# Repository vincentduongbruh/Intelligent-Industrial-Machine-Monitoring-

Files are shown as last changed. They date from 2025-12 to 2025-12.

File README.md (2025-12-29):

# Intelligent Industrial Motor Monitoring

**Real-Time Fault Detection Using Current, Vibration, and Temperature Sensing**

This project presents an intelligent motor health monitoring system designed to detect early-stage electrical and mechanical faults in industrial motors. The system continuously measures **3-phase current**, **vibration**, and **temperature**, analyzes these signals in real time, and visualizes motor health indicators through a graphical user interface (GUI).

The work was conducted in collaboration with **NASA Ames Research Center** and builds upon prior research on generalized fault detection using the **Filtered Park’s Vector Approach (FPVA)**. While traditional fault-detection methods often remain confined to offline analysis or simulation, this project focuses on a **deployable, sensor-driven monitoring platform** suitable for real-world industrial environments.

---

## Motivation

Induction motors account for approximately **90% of electrically driven industrial machinery**, including:
- Manufacturing robots
- CNC machines
- Conveyors
- HVAC systems
- Aerospace actuators and pumps

Despite their ubiquity, motor faults such as **bearing wear**, **shaft misalignment**, **gear damage**, and **electrical phase imbalance** often go undetected until catastrophic failure. These faults manifest as changes in:
- Current signatures
- Vibration spectra
- Operating temperature

This project bridges the gap between **fault-detection algorithms** and **physical monitoring infrastructure**, enabling early detection and improved system reliability.

---

## System Overview

The system is composed of three primary subsystems:

1. **Temperature & Vibration Sensing PCB**
2. **3-Phase Current Sensing PCB**
3. **Data Processing Server and GUI**

Sensor data is transmitted to the processing server via a combination of **USB** and **Bluetooth Low Energy (BLE)** links.

> Note: Due to limited access to industrial induction motors, testing was performed using **ESC-driven brushless motors**. While this changes the expected current waveforms, the monitoring approach remains applicable to industrial motors and VFD-driven systems.

---

## Hardware Architecture

### Sensors
- **Temperature**: Dual SHT30 temperature sensors mounted near motor windings
- **Vibration**: Dual MPU6500 IMUs measuring linear acceleration
- **Current**: Non-invasive current transformer measuring 3-phase current

### Electronics
- **ESP32 Microcontrollers**
  - One ESP32 for temperature & vibration sensing
  - One ESP32 for high-speed current acquisition

### Physical Testing Rig
- Custom **3D-printed rig** for:
  - Mechanical stability
  - Consistent sensor placement
  - Repeatable experiments

---

## Embedded Software

### Sensor Drivers
- Custom I2C drivers for temperature and IMU sensors
- Register-level configuration based on manufacturer datasheets
- Real-time data acquisition

### Sensor Calibration
- **Affine sensor model** used to correct bias and sensitivity
- Gravity-based calibration for IMUs
- Known-reference calibration for temperature sensors

### Signal Conditioning
- **Exponential Moving Average (EMA) low-pass filtering**
  - Reduces high-frequency noise
  - Lightweight and suitable for real-time embedded systems

### Communication
- **BLE (1 kHz)**: Temperature and vibration data
- **USB (10 kHz)**: Phase-accurate 3-phase current data
  - Chosen to avoid wireless latency and phase misalignment

---

## Data Processing

### Park’s Vector Approach
- Converts 3-phase currents into the rotating **d–q reference frame**
- Enables fault detection through geometric patterns in the id–iq plane

Under ideal conditions:
- Healthy motor → circular Park’s Vector trajectory
- Faulted motor → distorted or asymmetric trajectory

For ESC-driven motors:
- Healthy motor → six-pointed star pattern
- Phase fault → collapsed or triangular pattern

The system adapts the interpretation of Park’s Vector results based on the motor drive method.

---

## Graphical User Interface (GUI)

The GUI provides real-time visualization of:

1. **3-Phase Current Waveforms**
2. **Filtered Park’s Vector Plot**
3. **Vibration (Time + Frequency Domain)**
   - RMS vibration
   - FFT-based frequency analysis
4. **Temperature Monitoring**

Threshold-based alerts notify the user of potential electrical or mechanical faults.

---

## Testing and Validation

Fault conditions were intentionally introduced to validate system behavior:
- **Phase imbalance** via diode-induced waveform distortion
- **Mechanical vibration** using off-center rotating loads
- **Thermal stress** via high-throttle motor operation

The system consistently distinguished healthy and faulted operating states across current, vibration, and temperature modalities.

---

## Challenges and Limitations

- **Wireless latency** caused phase misalignment (resolved by USB current transmission)
- **ESC-driven motors** produce non-sinusoidal waveforms
- **High sampling rates** (≥10 kHz) required for accurate current analysis
- Limited access to industrial induction motors for final validation

---

## Future Work

- Deploy and validate system on industrial induction motors
- Apply machine learning for **multi-class fault classification**
- Extract higher-level features from current, vibration, and thermal data
- Improve fault localization and severity estimation

---

## Team

- **Nick Bui**
- **Mohamed Homsi**
- **Aashrith Beesabathuni**
- **Vincent Duong**
- **Carter Chen**

---

## Acknowledgements

We thank:
- Professor Dutta
- Paul De La Sayette
- Matteo Guarrera
- Dr. Rodney Martin
- Isak Bolin (NASA Ames Research Center)

for their guidance and foundational research support.

---

## References

- Bolin, I. *Generalized Fault Detection of Broken Rotor Bars in Induction Motors*, Uppsala University, 2024.

---

## To run GUI on Raspberry Pi or Laptop: 
<pre>cd src/raspberry_pi </pre>
<pre>python -m venv env</pre>
<pre>source env/bin/activate</pre>
<pre>pip install -r requirements.txt</pre>
<pre>python gui.py</pre>

## Troubleshooting FAQ:
#### BLE Connection Failing: 
- Ctrl+C to terminate
- Reset ESP 1
- <pre>python gui.py</pre>
#### CT Data Missing:
- Ctrl+C to terminate
- Reset ESP2
- <pre>python gui.py</pre>

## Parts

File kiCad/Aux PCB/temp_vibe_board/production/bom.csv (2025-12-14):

Designator | Footprint | Quantity | Value | LCSC Part #
C1, C2, C3, C4 | 0805 | 4 | 0.1 uF
J1, J9 | PinHeader_1x04_P2.54mm_Horizontal | 2 | Conn_01x04_Pin
R1, R2, R3, R4 | 0805 | 4 | 4.7 K
U1 | MODULE_DEV-13907 | 1 | DEV-13907
U2, U6 | MPU6500 | 2 | MPU-6500

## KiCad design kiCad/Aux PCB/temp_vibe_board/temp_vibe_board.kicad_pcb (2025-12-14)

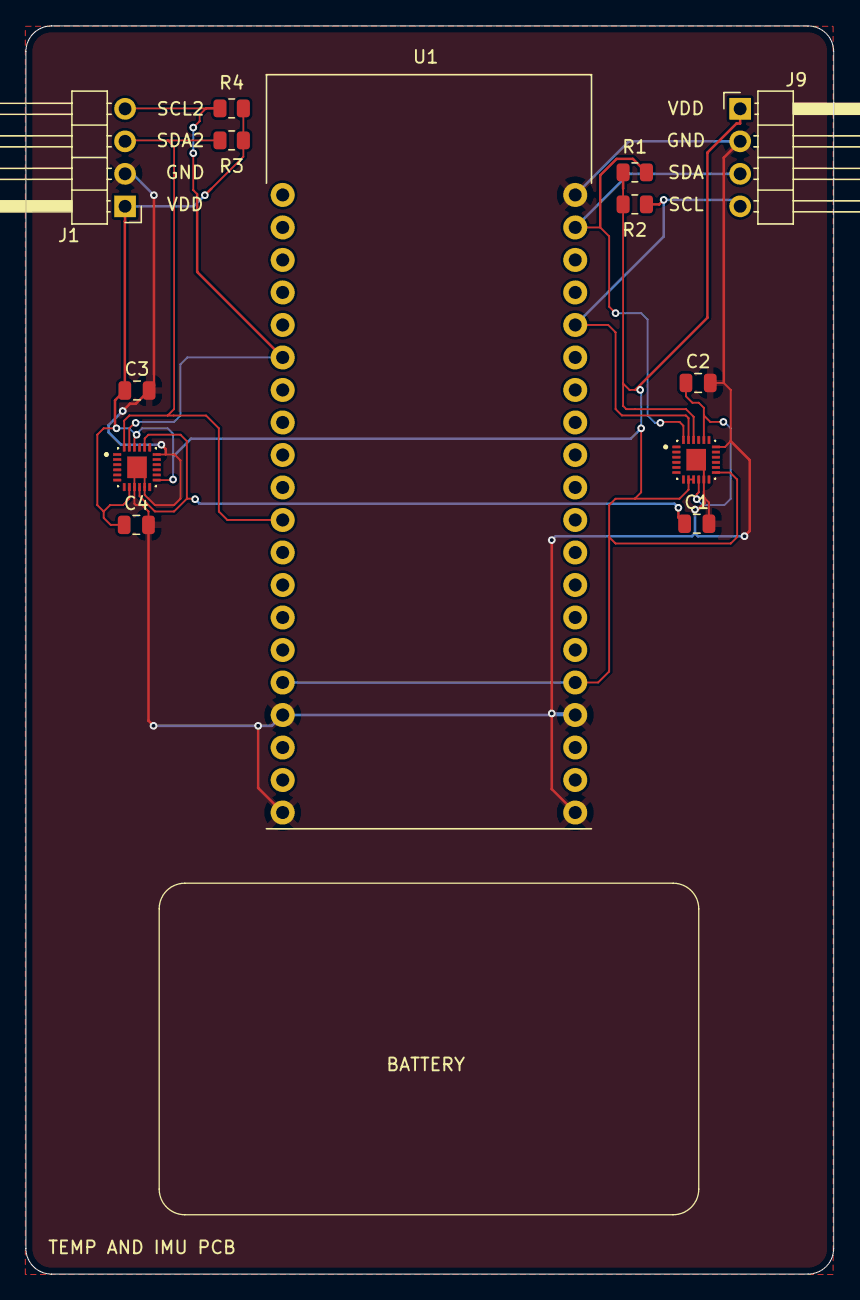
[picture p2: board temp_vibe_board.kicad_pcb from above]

Board: 2 copper layers, 63.1 x 97.5 mm, 13 parts (0 on the bottom side), 8 nets.

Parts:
C1, C2, C3, C4: 0.1 uF; C_0805_2012Metric
J1, J9: Conn_01x04_Pin; PinHeader_1x04_P2.54mm_Horizontal
R1, R2, R3, R4: 4.7 K; R_0805_2012Metric
U1: DEV-13907; MODULE_DEV-13907
U2, U6: MPU-6500; MPU6500

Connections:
GND: C1.2, C2.2, C3.2, C4.2, J1.2, J9.2, U1.J1_1 (GND), U1.J1_4 (GND), U1.J2_1 (GND), U1.J2_4 (GND), U1.J2_20 (GND), U2.11 (FSYNC), U2.18 (GND), U2.25 (EXP), U6.9 (AD0/SDO), U6.11 (FSYNC), U6.18 (GND), U6.25 (EXP)
unnamed: C2.1, U2.10 (REGOUT), U2.20 (RESV_2)
unnamed: C1.1, U6.10 (REGOUT), U6.20 (RESV_2)
SCL: J9.4, R1.2, U1.J2_16 (U0_RTS/V_SPI_WP/GPIO22/SCL/22), U2.23 (SCL/SCLK)
SCL2: J1.4, R4.2, U1.J1_15 (TOUCH8/ADC1_5/GPIO33/XTAL32/33), U6.23 (SCL/SCLK)
SDA: J9.3, R2.2, U1.J2_19 (V_SPI_HD/GPIO21/SDA/21), U2.24 (SDA/SDI)
SDA2: J1.3, R3.2, U1.J1_10 (TOUCH7/ADC2_7/GPIO27/27), U6.24 (SDA/SDI)
VDDIO: C3.1, C4.1, J1.1, J9.1, R1.1, R2.1, R3.1, R4.1, U1.J1_5 (3.3V/3V3), U1.J2_5 (3.3V/3V3), U2.8 (VDDIO), U2.9 (AD0/SDO), U2.13 (VDD), U2.22 (NCS), U6.8 (VDDIO), U6.13 (VDD), U6.22 (NCS)

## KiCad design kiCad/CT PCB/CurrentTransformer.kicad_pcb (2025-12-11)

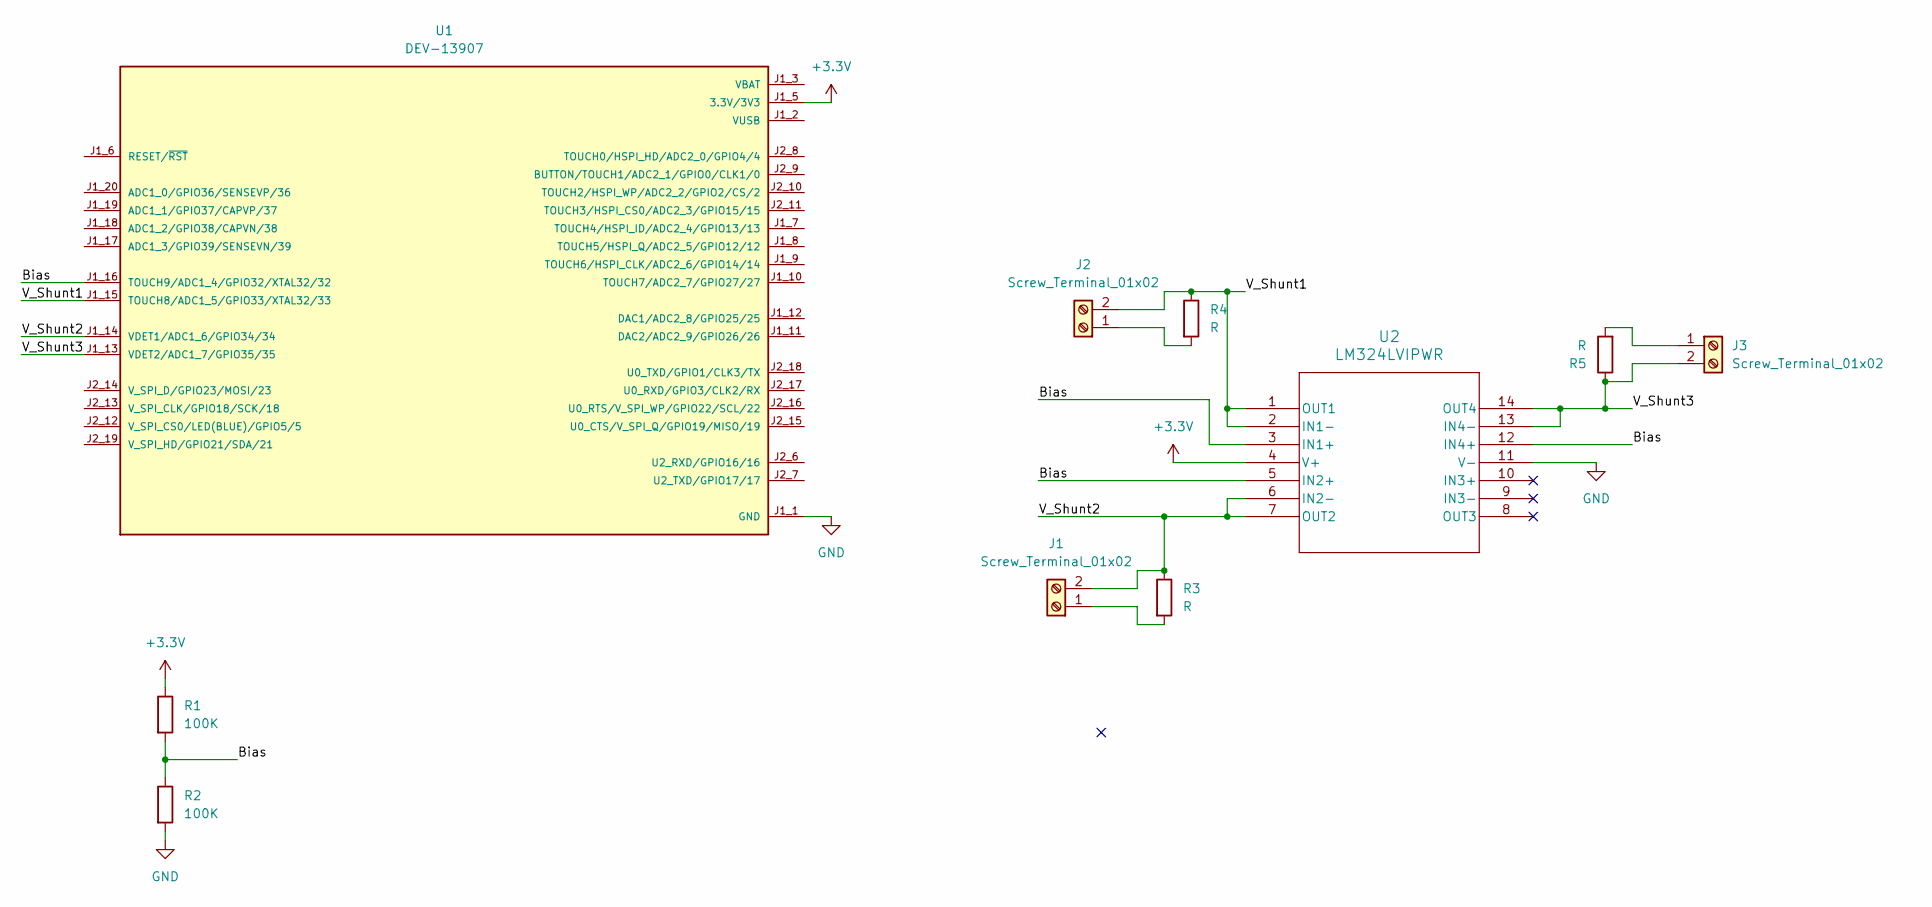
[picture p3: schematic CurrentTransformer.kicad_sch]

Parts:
J1, J2, J3: Screw_Terminal_01x02; OST_OSTTE020104
R1, R2: 100K; R_0603_1608Metric
R3, R4, R5: R; R_Axial_DIN0207_L6.3mm_D2.5mm_P10.16mm_Horizontal
U1: DEV-13907; MODULE_DEV-13907; PARTREV V10
U2: LM324LVIPWR; PW14_TEX-L

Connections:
+3.3V: R1.1, U1.J1_5 (3.3V/3V3), U1.J2_5 (3.3V/3V3), U2.4 (V+)
/Bias: R1.2, R2.1, U1.J1_16 (TOUCH9/ADC1_4/GPIO32/XTAL32/32), U2.3 (IN1+), U2.5 (IN2+), U2.12 (IN4+)
/V_Shunt1: J2.2, R4.1, U1.J1_15 (TOUCH8/ADC1_5/GPIO33/XTAL32/33), U2.1 (OUT1), U2.2 (IN1-)
/V_Shunt2: J1.2, R3.1, U1.J1_14 (VDET1/ADC1_6/GPIO34/34), U2.6 (IN2-), U2.7 (OUT2)
/V_Shunt3: J3.2, R5.1, U1.J1_13 (VDET2/ADC1_7/GPIO35/35), U2.13 (IN4-), U2.14 (OUT4)
GND: R2.2, U1.J1_1 (GND), U1.J1_4 (GND), U1.J2_1 (GND), U1.J2_4 (GND), U1.J2_20 (GND), U2.11 (V-)
unnamed: J1.1, R3.2
unnamed: J2.1, R4.2
unnamed: J3.1, R5.2
VBAT: U1.J1_3 (VBAT), U1.J2_3 (VBAT)
VUSB: U1.J1_2 (VUSB), U1.J2_2 (VUSB)

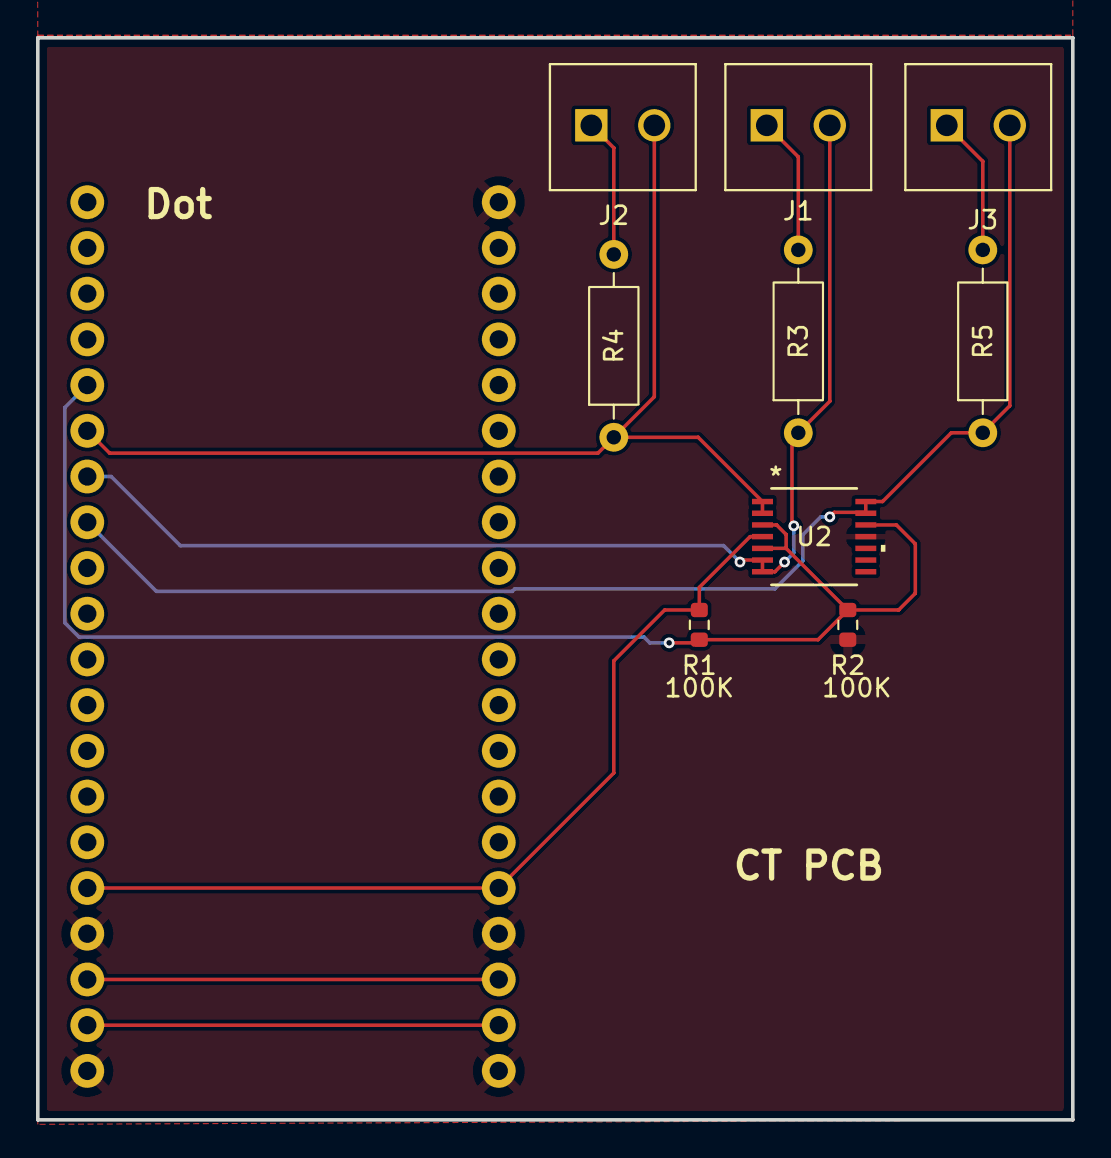
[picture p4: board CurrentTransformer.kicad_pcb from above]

Board: 2 copper layers, 57.5 x 60.1 mm, 10 parts (1 on the bottom side), 11 nets.

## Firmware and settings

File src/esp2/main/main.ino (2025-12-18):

// #include "ThreePhaseCurrentPacket.h"
// #include "ESPNowTransmitter.h"
#include "ADC.h"

// const uint8_t RECEIVER_MAC_ADDR[] = {0x30, 0xAE, 0xA4, 0x05, 0x96, 0xC4};
// ESPNowTransmitter esp_transmitter(RECEIVER_MAC_ADDR);
// ThreePhaseCurrentPacket packet;

const int BIAS_PIN = 32;
const int SHUNT_PIN_1 = 36;
const int SHUNT_PIN_2 = 37;
const int SHUNT_PIN_3 = 38;


const float R_SHUNT = 680;
const float ADC_REF = 3.3;
const int ADC_MAX = 4095;
const int SAMPLE_COUNT = 256;
const uint32_t SAMPLE_DELAY_US = 500;  // ~2 kHz for 50/60 Hz content
const float CT_SENS_V_PER_A = 0.556f;  // ~0.556 V/A RMS at ADC node
const float TURNS_RATIO = 3100;

void setup() {
  Serial.begin(115200);
  adc_configure(SHUNT_PIN_1, 12, ADC_11db);
  adc_configure(SHUNT_PIN_2, 12, ADC_11db);
  adc_configure(SHUNT_PIN_3, 12, ADC_11db);

  // if (!esp_transmitter.begin()) {
  //   Serial.println("ESP-Now transmitter: Fail");
  //   delay(100);
  // }
  // Serial.println("ESP-NOW transmitter: Ready");
}

void loop() {
  // packet.ia = adc_read_voltage(SHUNT_PIN_1) / R_SHUNT;
  // packet.ib = adc_read_voltage(SHUNT_PIN_2) / R_SHUNT;
  // packet.ic = adc_read_voltage(SHUNT_PIN_3) / R_SHUNT;

  float ia, ib, ic;
  float bias = adc_read_voltage(BIAS_PIN);
  ia = (adc_read_voltage(SHUNT_PIN_1) - bias) / R_SHUNT * TURNS_RATIO;
  ib = (adc_read_voltage(SHUNT_PIN_1) - bias) / R_SHUNT * TURNS_RATIO;
  ic = (adc_read_voltage(SHUNT_PIN_1) - bias) / R_SHUNT * TURNS_RATIO;

  Serial.printf("ia:%0.5f ib:%0.5f ic:%0.5f\n",
              ia, ib, ic);

  // esp_transmitter.send(packet);
  delay(0.1);
}

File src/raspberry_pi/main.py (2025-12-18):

import asyncio
import struct
import time
import re
import threading
from collections import deque

import numpy as np
import serial
from bleak import BleakScanner, BleakClient, BleakError
import pandas as pd
import os

from fault import MotorFaultDetector

DEVICE_NAME = "ESP32_1"
CHAR_UUID = "488147e4-8512-4bca-b218-0b84f2f76853"

# ---------- Serial ----------
SERIAL_PORT = "/dev/tty.usbserial-D306EM4X"
BAUDRATE = 115200

ser = None

LINE_REGEX = re.compile(
    r"ia:([-+]?\d*\.?\d+)\s+"
    r"ib:([-+]?\d*\.?\d+)\s+"
    r"ic:([-+]?\d*\.?\d+)"
)

def open_serial(port: str, baud: int) -> serial.Serial:
    ser = serial.Serial(port, baud, timeout=0.1)  # short timeout
    time.sleep(1.5)
    return ser

def parse_line(line: str):
    m = LINE_REGEX.search(line)
    if not m:
        return None
    return float(m.group(1)), float(m.group(2)), float(m.group(3))

# Latest serial values updated by background thread
latest_currents = {"ia": None, "ib": None, "ic": None, "t": None}

def serial_reader_loop(ser: serial.Serial, stop_event: threading.Event):
    """Continuously read serial lines and update latest_currents."""
    while not stop_event.is_set():
        try:
            line = ser.readline().decode(errors="ignore").strip()
            if not line:
                continue
            vals = parse_line(line)
            if vals is None:
                continue
            ia, ib, ic = vals
            latest_currents["ia"] = ia
            latest_currents["ib"] = ib
            latest_currents["ic"] = ic
            latest_currents["t"] = time.time()
        except Exception:
            # swallow serial parse errors
            continue

# ---------- GUI global (set by motor_gui.py) ----------
class GUIRegistry:
    def __init__(self):
        self.app = None

gui_app = GUIRegistry()
start_time = None

def run_data_acquisition():
    """
    Entry point used by motor_gui.py.
    Runs the BLE + serial acquisition loop in the calling thread.
    """
    asyncio.run(main())

# ---------- Fault detector ----------
fault_detector = MotorFaultDetector(fs_target=3600, f0_target=60)

BUFFER_SIZE = 200
buf = {
    "ia": deque(maxlen=BUFFER_SIZE),
    "ib": deque(maxlen=BUFFER_SIZE),
    "ic": deque(maxlen=BUFFER_SIZE),
}

def callback_handler(sender: int, data: bytearray):
    """BLE notification callback."""
    global start_time, gui_app

    if start_time is None:
        start_time = time.time()

    t = time.time() - start_time

    # 1) Confirm we are receiving notifications
    print(f"BLE notify: {len(data)} bytes")

    # 2) Decode BLE payload safely (don’t crash)
    ax = ay = az = temp = 0.0
    try:
        # Common case: 4 floats = 16 bytes (ax,ay,az,temp)
        if len(data) >= 16:
            ax, ay, az, temp = struct.unpack("<4f", data[:16])
    except Exception as e:
        print(f"⚠️ BLE unpack error: {e}")

    # 3) Get latest serial currents without blocking BLE
    ia = latest_currents["ia"]
    ib = latest_currents["ib"]
    ic = latest_currents["ic"]

    # if ia is None or ib is None or ic is None:
    #     return
        
    # if ia == 0.0 or ib == 0.0 or ic == 0.0:
    #     return
    
    row_dict = {"time": [t], "ia": [ia], "ib": [ib], "ic": [ic]}
    df = pd.DataFrame(row_dict)
    
    output_path = "data.csv"
    df.to_csv(output_path, mode='a', index=False, header=not os.path.exists(output_path))

    data = {"time": [t], "ia": [ia], "ib": [ib], "ic": [ic]}
    # print(data)

    # df = pd.DataFrame(data, columns=["time", "ia", "ib", "ic"])
    # print(df)

    # dataframe to csv for current
    # file_number = 1
    # output_path = f"current_{file_number}.csv"

    # while os.path.isfile(output_path):
    #     file_number += 1
    # df.to_csv(output_path, index=False)
    # df.to_csv(output_path, mode='a', header=not os.path.exists(output_path))

    if ia is None or ib is None or ic is None:
        # Serial not ready yet; still show IMU
        print(f"IMU only: ax={ax:.3f} ay={ay:.3f} az={az:.3f} temp={temp:.2f}")
        return

    print(
        f"ax={ax:.3f}, ay={ay:.3f}, az={az:.3f}, temp={temp:.2f} | "
        f"ia={ia:.3f}, ib={ib:.3f}, ic={ic:.3f}"
    )

    # 4) DC removal (critical for Park)
    buf["ia"].append(ia)
    buf["ib"].append(ib)
    buf["ic"].append(ic)

    ia_ac = ia - float(np.mean(buf["ia"]))
    ib_ac = ib - float(np.mean(buf["ib"]))
    ic_ac = ic - float(np.mean(buf["ic"]))

    # if ia_ac is None or ib_ac is None or ic_ac is None:
    #     return
        
    # if ia_ac == 0.0 or ib_ac == 0.0 or ic_ac == 0.0:
    #     return
    
    # dataframe to csv for current_ac
    # row_dict = {"time": [t], "ia": [ia_ac], "ib": [ib_ac], "ic": [ic_ac]}
    # df = pd.DataFrame(row_dict, columns=["time", "ia", "ib", "ic"])

    # file_number = 1
    # output_path = f"current_ac_{file_number}.csv"

    # while os.path.isfile(output_path):
    #     file_number += 1
    # df.to_csv(output_path, index=False)
    
    # output_path = "test3.csv"
    # df.to_csv(output_path, mode='a', index=False, header=not os.path.exists(output_path))

    # 5) Park vector (and scaled trajectory) on DC-removed signals.
    # We intentionally do NOT run ODT or filtering here.
    #
    # Compute Park's vector for the entire buffered window, then scale the
    # trajectory, and take the most recent point for plotting.
    ia_ac_win = np.array(buf["ia"], dtype=float) - float(np.mean(buf["ia"]))
    ib_ac_win = np.array(buf["ib"], dtype=float) - float(np.mean(buf["ib"]))
    ic_ac_win = np.array(buf["ic"], dtype=float) - float(np.mean(buf["ic"]))

    id_win, iq_win = fault_detector.compute_park_vector(ia_ac_win, ib_ac_win, ic_ac_win)
    id_scaled_win, iq_scaled_win = fault_detector.scale_trajectory(id_win, iq_win)

    # Latest scaled point (used by GUI for the "Filtered" Park's vector plot)
    filtered_id = float(id_scaled_win[-1])
    filtered_iq = float(iq_scaled_win[-1])

    # Also expose the latest unscaled point (useful for debugging / optional plots)
    id_val = float(id_win[-1])
    iq_val = float(iq_win[-1])

    # 6) Update GUI if present
    if gui_app is not None:
        try:
            gui_app.add_data_point(
                t, ax, ay, az, temp, ia, ib, ic,
                id_val, iq_val,
                filtered_id, filtered_iq
            )
        except Exception as e:
            print(f"❌ GUI update error: {e}")
            gui_app = None

async def find_device():
    print("Scanning for ESP32...")
    devices = await BleakScanner.discover(timeout=5.0)
    for d in devices:
        if d.name and DEVICE_NAME in d.name:
            print(f"Found {d.name} [{d.address}]")
            return d
    raise RuntimeError("ESP32 not found")
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

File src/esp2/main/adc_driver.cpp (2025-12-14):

#include "adc_driver.h"

bool adc_configure(uint8_t pin,
                   uint8_t width_bits,
                   adc_attenuation_t attenuation) {
    // Configure ADC resolution globally and attenuation per pin.
    analogReadResolution(width_bits);
    analogSetPinAttenuation(pin, attenuation);
    return true;
}

uint16_t adc_read_raw(uint8_t pin) {
    int val = analogRead(pin);
    return (val < 0) ? 0 : static_cast<uint16_t>(val);
}

float adc_raw_to_voltage(uint16_t raw, float vref, uint16_t max_count) {
    if (max_count == 0) return 0.0f;
    return (static_cast<float>(raw) * vref) / static_cast<float>(max_count);
}

float adc_read_voltage(uint8_t pin, float vref, uint16_t max_count) {
    // Prefer calibrated millivolts if available in Arduino core.
    return static_cast<float>(adc_read_mv(pin)) / 1000.0f;
}

uint16_t adc_read_mv(uint8_t pin) {
    //  eFuse calibration for better accuracy compred to current ADC (from the arudino)
    int mv = analogReadMilliVolts(pin);
    return (mv < 0) ? 0 : static_cast<uint16_t>(mv);
}

uint16_t adc_read_rms_mv(uint8_t pin,
                         uint16_t sample_count,
                         uint32_t sample_delay_us) {
    if (sample_count == 0) return 0;

    float mean = 0.0f;
    float m2 = 0.0f; 

    for (uint16_t i = 1; i <= sample_count; i++) {
        float x = static_cast<float>(adc_read_mv(pin));
        float delta = x - mean;
        mean += delta / i;
        m2 += delta * (x - mean);
        if (sample_delay_us) delayMicroseconds(sample_delay_us);
    }

    float rms = sqrtf(m2 / sample_count);  // AC RMS (bias removed) in mV
    return static_cast<uint16_t>(rms);
}

float adc_read_rms_v(uint8_t pin,
                     uint16_t sample_count,
                     uint32_t sample_delay_us) {
    return static_cast<float>(adc_read_rms_mv(pin, sample_count, sample_delay_us)) / 1000.0f;
}

float adc_read_irms(uint8_t pin,
                    float volts_per_amp,
                    uint16_t sample_count,
                    uint32_t sample_delay_us) {
    if (volts_per_amp <= 0.0f) return 0.0f;
    float vrms = adc_read_rms_v(pin, sample_count, sample_delay_us);
    return vrms / volts_per_amp;
}

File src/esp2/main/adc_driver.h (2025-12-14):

#pragma once

#include <Arduino.h>
#include "esp32-hal-adc.h"  // for adc_attenuation_t

// Lightweight ADC helpers for ESP32 (Arduino core).
bool adc_configure(uint8_t pin,
                   uint8_t width_bits = 12,
                   adc_attenuation_t attenuation = ADC_11db);

uint16_t adc_read_raw(uint8_t pin);

float adc_raw_to_voltage(uint16_t raw,
                         float vref = 3.3f,
                         uint16_t max_count = 4095);

float adc_read_voltage(uint8_t pin,
                       float vref = 3.3f,
                       uint16_t max_count = 4095);

uint16_t adc_read_mv(uint8_t pin);  // calibrated mV via analogReadMilliVolts


uint16_t adc_read_rms_mv(uint8_t pin,
                         uint16_t sample_count = 256,
                         uint32_t sample_delay_us = 500);

float adc_read_rms_v(uint8_t pin,
                     uint16_t sample_count = 256,
                     uint32_t sample_delay_us = 500);

float adc_read_irms(uint8_t pin,
                    float volts_per_amp,
                    uint16_t sample_count = 256,
                    uint32_t sample_delay_us = 500);

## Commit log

2025-11-13 Current Transformer
2025-11-14 Temp and Accelerometer Integrated
2025-11-19 CT ESP Folder Fix
    [main.ino]
2025-11-23 Add files via upload
    CT
    [CurrentTransformer-B_Cu.gbr, CurrentTransformer-B_Mask.gbr, CurrentTransformer-B_Paste.gbr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]
2025-12-03 MPU9250 Calibration and Integration
2025-12-03 Added EMA LP Filtering and Integrated into IMU and Temp Reads
2025-12-04 AUX PCB Upload
    [temp_vibe_board.kicad_pcb, temp_vibe_board.kicad_sch]
2025-12-04 PCB files
2025-12-09 debug sensor data
2025-12-10 Debuggin I2C and Clean Up
2025-12-11 fix merge conflicts
    [CurrentTransformer.kicad_pcb, CurrentTransformer.kicad_sch]
2025-12-17 switching to uart
2025-12-17 working uart
2025-12-18 more data
    [test.csv, test2.csv, test3.csv]
2025-12-18 E2E done
    [test2.csv, test3.csv]
2025-12-18 attempt at interpolation
    [test2.csv, test3.csv]
2025-12-18 GUI Working, CSV for Processing
    [current_1.csv, current_ac_1.csv, test2.csv]
2025-12-18 10 KHz
    [cleaned_test.csv, current_1.csv, current_ac_1.csv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]
2025-12-18 Diode Motor Fault
    [data.csv, diode.csv]
2025-12-18 Diode Fault
    [diode.csv]
